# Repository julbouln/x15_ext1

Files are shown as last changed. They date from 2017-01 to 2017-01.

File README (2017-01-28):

Simple extension board for Beagleboard X15, eagle schematics and layout included.

Main purpose is to add an LVDS interface through video out and SN75LVDS83B chip and some GPIO and stuff on hackable pin headers. It uses only P18 Beagleboard X15 port and measure 55.88x43.18mm.

Pin headers includes : 
- 2 3V3, 5V, 12V with GND pins, 
- 8 single channel LVDS pins
- X15 power off pin 
- 14 GPIOS which should be used as I2C(1), SPI(1), PWM(2?) and UART(2?).

Included my DTS files (tested on linux 4.9.4 and 4.4.44) for an AUO B156XW04 V5 screen (GPIO4_7 as EN, EHRPWM2B as backlight), as well as a ruby script to convert from EDID hex file to "panel-timing" node.

To recompile DTB :
$ git clone https://github.com/RobertCNelson/dtb-rebuilder
$ cd dtb-rebuilder
$ cp ../x15_ext1/linux/am57xx-beagle-x15.dts src/arm
$ make src/arm/am57xx-beagle-x15.dtb

Unfortunately for 1366 width display, kernel need to be modified and recompiled.
Edit drivers/gpu/drm/omapdrm/dss/dpi.c then comment theses lines :
//   if (timings->x_res % 8 != 0)
//	return -EINVAL;
Not sure why there is this restriction since it seems to work without it.

Limitations and errata:
- only 18 bits single channel LVDS screens are supported
- LVDS positive pin 1 and LVDS positive pin 2 are inversed

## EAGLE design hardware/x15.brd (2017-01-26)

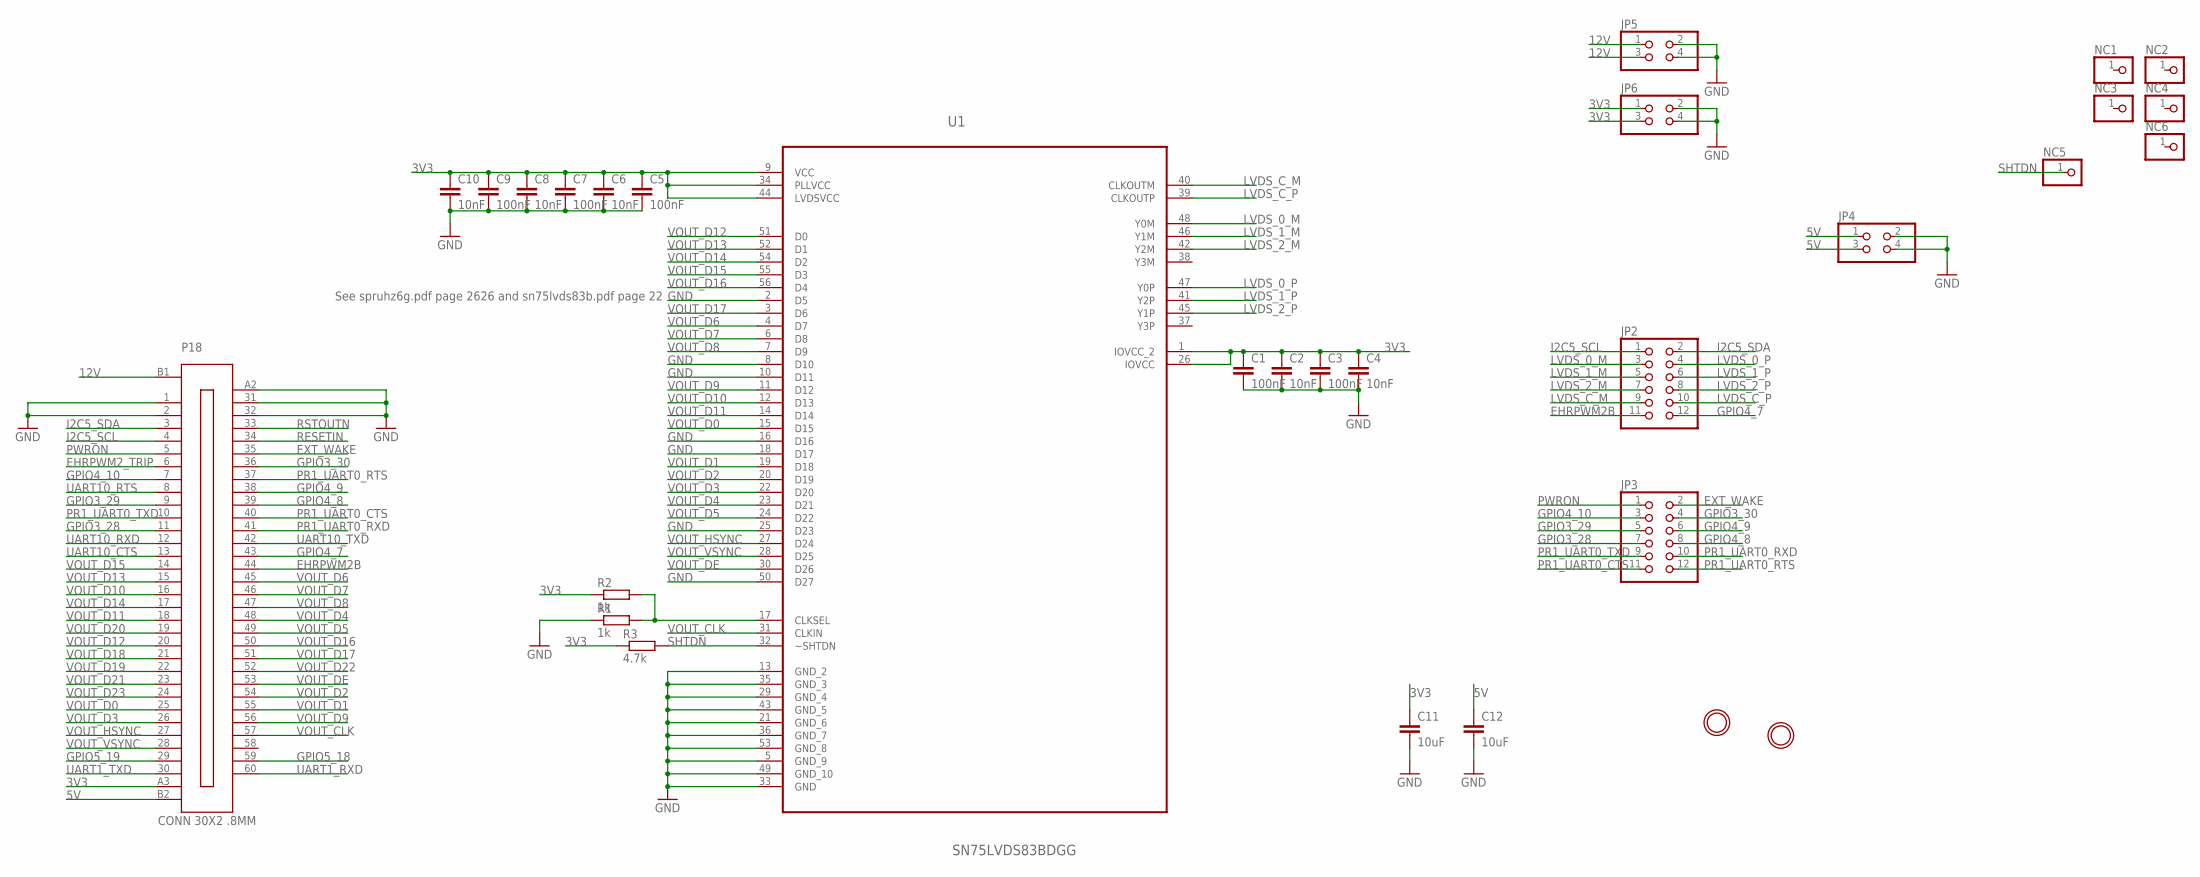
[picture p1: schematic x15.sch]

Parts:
C1, C3, C5, C7, C9: 100nF; C0603K
C2, C4, C6, C8, C10: 10nF; C0603K
C11, C12: 10uF; C1206K
JP2, JP3: PINHD-2X6; 2X06
JP4, JP5, JP6: PINHD-2X2; 2X02
NC1, NC2, NC3, NC4, NC5, NC6: PINHD-1X1; 1X01
P18: CONN 30X2 .8MM; CONN_FX18-60S-0.8SV15
R1, R2: 1k; R0603
R3: 4.7k; R0603
U1: SN75LVDS83BDGG; SOP50P810X120-56N
U$1, U$2: MOUNTINGHOLE2.5; MOUNTINGHOLE_2.5_PLATED

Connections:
3V3: C1.1, C2.1, C3.1, C4.1, C5.1, C6.1, C7.1, C8.1, C9.1, C10.1, C11.1, JP6.1, JP6.3, P18.A3, R2.1, R3.1, U1.1 (IOVCC_2), U1.9 (VCC), U1.26 (IOVCC), U1.34 (PLLVCC), U1.44 (LVDSVCC)
5V: C12.1, JP4.1, JP4.3, P18.B2
12V: JP5.1, JP5.3, P18.B1
EHRPWM2B: JP2.11, P18.44
EHRPWM2_TRIP: P18.6
EXT_WAKE: JP3.2, P18.35
GND: C1.2, C2.2, C3.2, C4.2, C5.2, C6.2, C7.2, C8.2, C9.2, C10.2, C11.2, C12.2, JP4.2, JP4.4, JP5.2, JP5.4, JP6.2, JP6.4, P18.1, P18.2, P18.31, P18.32, P18.A2, R1.1, U1.2 (D5), U1.5 (GND_9), U1.8 (D10), U1.10 (D11), U1.13 (GND_2), U1.16 (D16), U1.18 (D17), U1.21 (GND_6), U1.25 (D23), U1.29 (GND_4), U1.33 (GND), U1.35 (GND_3), U1.36 (GND_7), U1.43 (GND_5), U1.49 (GND_10), U1.50 (D27), U1.53 (GND_8)
GPIO3_28: JP3.7, P18.11
GPIO3_29: JP3.5, P18.9
GPIO3_30: JP3.4, P18.36
GPIO4_7: JP2.12, P18.43
GPIO4_8: JP3.8, P18.39
GPIO4_9: JP3.6, P18.38
GPIO4_10: JP3.3, P18.7
GPIO5_18: P18.59
GPIO5_19: P18.29
I2C5_SCL: JP2.1, P18.4
I2C5_SDA: JP2.2, P18.3
LVDS_0_M: JP2.3, U1.48 (Y0M)
LVDS_0_P: JP2.4, U1.47 (Y0P)
LVDS_1_M: JP2.5, U1.46 (Y1M)
LVDS_1_P: JP2.6, U1.41 (Y2P)
LVDS_2_M: JP2.7, U1.42 (Y2M)
LVDS_2_P: JP2.8, U1.45 (Y1P)
LVDS_C_M: JP2.9, U1.40 (CLKOUTM)
LVDS_C_P: JP2.10, U1.39 (CLKOUTP)
unnamed: R1.2, R2.2, U1.17 (CLKSEL)
PR1_UART0_CTS: JP3.11, P18.40
PR1_UART0_RTS: JP3.12, P18.37
PR1_UART0_RXD: JP3.10, P18.41
PR1_UART0_TXD: JP3.9, P18.10
PWRON: JP3.1, P18.5
RESETIN: P18.34
RSTOUTN: P18.33
SHTDN: NC5.1, R3.2, U1.32 (~SHTDN)
UART1_RXD: P18.60
UART1_TXD: P18.30
UART10_CTS: P18.13
UART10_RTS: P18.8
UART10_RXD: P18.12
UART10_TXD: P18.42
VOUT_CLK: P18.57, U1.31 (CLKIN)
VOUT_D0: P18.25, U1.15 (D15)
VOUT_D1: P18.55, U1.19 (D18)
VOUT_D2: P18.54, U1.20 (D19)
VOUT_D3: P18.26, U1.22 (D20)
VOUT_D4: P18.48, U1.23 (D21)
VOUT_D5: P18.49, U1.24 (D22)
VOUT_D6: P18.45, U1.4 (D7)
VOUT_D7: P18.46, U1.6 (D8)
VOUT_D8: P18.47, U1.7 (D9)
VOUT_D9: P18.56, U1.11 (D12)
VOUT_D10: P18.16, U1.12 (D13)
VOUT_D11: P18.18, U1.14 (D14)
VOUT_D12: P18.20, U1.51 (D0)
VOUT_D13: P18.15, U1.52 (D1)
VOUT_D14: P18.17, U1.54 (D2)
VOUT_D15: P18.14, U1.55 (D3)
VOUT_D16: P18.50, U1.56 (D4)
VOUT_D17: P18.51, U1.3 (D6)
VOUT_D18: P18.21
VOUT_D19: P18.22
VOUT_D20: P18.19
VOUT_D21: P18.23
VOUT_D22: P18.52
VOUT_D23: P18.24
VOUT_DE: P18.53, U1.30 (D26)
VOUT_HSYNC: P18.27, U1.27 (D24)
VOUT_VSYNC: P18.28, U1.28 (D25)

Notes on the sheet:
See spruhz6g.pdf page 2626 and sn75lvds83b.pdf page 22

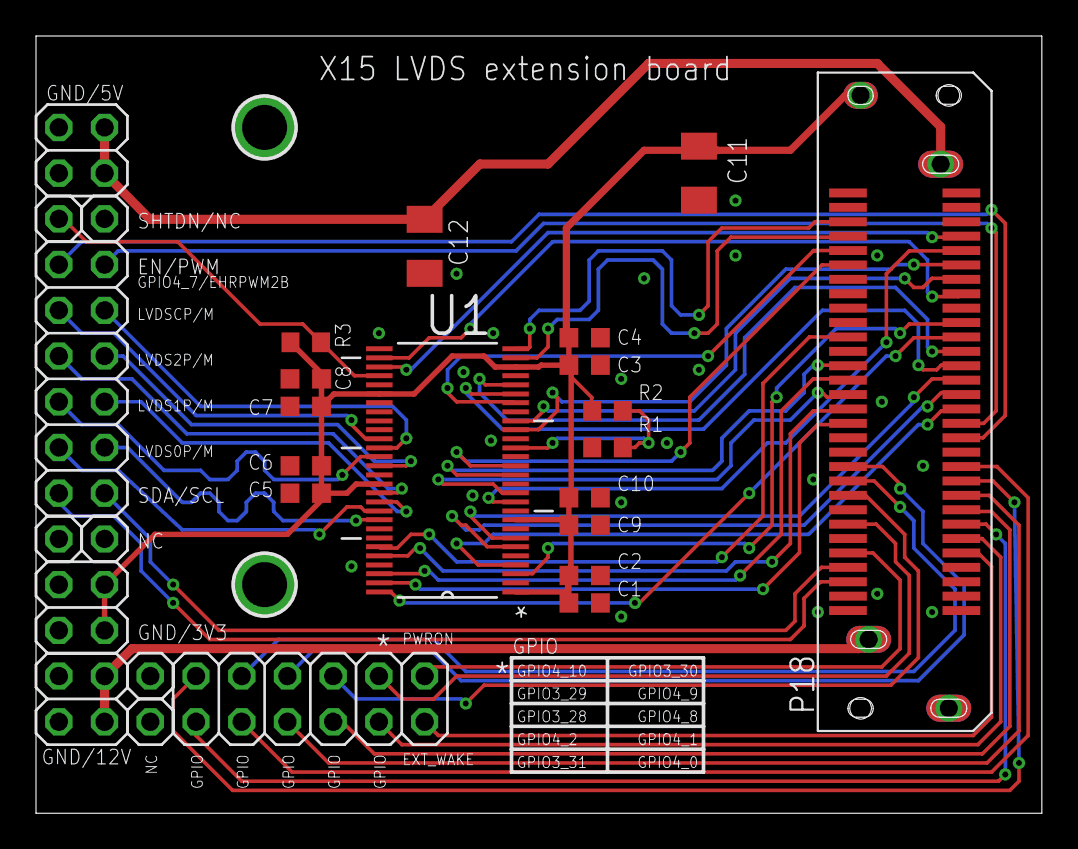
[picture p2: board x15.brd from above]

Board: 2 copper layers, 55.9 x 43.2 mm, 30 parts (0 on the bottom side), 52 nets.

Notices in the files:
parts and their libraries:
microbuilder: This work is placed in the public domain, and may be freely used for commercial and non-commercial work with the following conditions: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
